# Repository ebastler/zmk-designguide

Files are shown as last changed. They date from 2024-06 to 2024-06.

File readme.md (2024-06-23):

## Please note: This guide in its latest revision has just been published and may contain spelling mistakes as well as explanations referring to wrong components due to being written at an earlier stage, before re-annotation of the schematic. Please report any possible erorrs.

## Introduction

Since it's launch a few years ago, [ZMK](https://zmkfirmware.dev/), an open source firmware for (mainly wireless) custom keyboards, has grown in both features and userbase rapidly and I have recently designed multiple boards making use of it in the past. Questions about how to design ZMK compatible hardware have been getting more common, and the first edition of my guide was a crude attempt at answering those. The third revision - which is only the second revision of the guide, but based on the third generation of wireless designs I made - is a more advanced and refined approach. It still contains all Rev 1 circuitry, but with small improvements, and multiple more "advanced" alternative schematic snippets, as well as better explanations and descriptions.

Most keyboard design guides focus heavily on QMK (and QMK compatible MCUs). While ZMK works flawlessly on STM32 (e.G STM32F303) and PCBs for those can be designed the same way as QMK compatible PCBs would be, the main appeal of ZMK is wireless operation, and I will focus on a nRF52840 based design in this guide. Keep in mind, this is no official ZMK team related guide - just a reference implementation from a user, for users. If you notice any errors, please report them either through github, or by contacting me some other way in order for me to fix them.

This is a rather advanced guide that expects some basic electronics knowledge, as well as design and routing experience. If you do not have those, i would recommend going over the [ai03 PCB design guide](https://wiki.ai03.com/books/pcb-design/page/pcb-guide-part-1---preparations) first. It's a great explanation of most basics needed to design your first keyboard.

Many symbols (and/or their matching footprints) in this guide are taken from [marbastlib](https://github.com/ebastler/marbastlib), a keyboard-focused open source library of kicad footprints and symbols maintained by me and [MarvFPV](https://github.com/marvfpv). While it is possible to use different libraries, I recommend sticking to it, since it's footprints/symbols are tested and confirmed working. While it used to be installed as a submodule to the project folder, we have now moved it to the KiCad pakcage manager system with KiCad 7. An installation guide can be found in the repo linked above.

## Table of contents
* [Introduction](#Introduction)
* [What do I need for a Bluetooth keyboard?](#What-do-I-need-for-a-Bluetooth-keyboard)
* [This is too complicated for me!](#This-is-too-complicated-for-me)
* [Schematics and design considerations](#Schematics-and-design-considerations)
    * [USB connector and protections](#USB-connector-and-protections)
    * [Battery management](#Battery-management)
    * [MCU](#MCU)
    * [Switch matrix](#Switch-matrix)
    * [Optional - Vsense](#Vsense)
    * [Optional - Underglow](#Underglow)

## What do I need for a Bluetooth keyboard?
This section lists the important parts, as well as some basic considerations. Detailed explanations follow below. There is plenty of compatible parts that work well, some may even work better than the ones I chose. This is, however, focused around parts I am familiar with and have already prototyped to ensure proper operation. I will list multiple options, ranging from simpler to more complicated and advanced, usually also more expensive choices. Which is right for you depends on your budget, capabilities and requirements, so I opted for leaving you with multiple choices.

* **USB Port and protections**: For flashing, possible wired operation and, most importantly, charging, you still need a USB port. I went with a USB-C port. The HRO M12 and M14 type connectors are cheap and easy to source, easily hand-solderable and routable and provide great mechanical stability. The protections I chose on this PCB are a good compromise between cost, PCB estate and protections - offering enough protection for a keyboard, while being easy to route. I added a JST 4-pin SH connector as an alternative, which can be used to connect an ai03 unified compatible USB daughterboard.

* **Battery management**: There's lots of different controllers for this application. I will show you two possible choices, a cheaper and a more expensive (but also more feature-rich one). They both are available at jlcpcb for prototyping, easy to route, and offer programmable charge current - allowing to set it to the maximum USB 2.0 allows (500 mA). Power switches are optional, due to ZMKs astonishingly low idle power draw, but examples were included anyway. 

* **Battery**: Not much to say here. Pick any decent LiIon/LiPo single cell battery that fits your keyboard. More capacity = longer battery life. You can consult the [ZMK Power Profiler](https://zmk.dev/power-profiler) to get a rough estimate of your expected battery life. Try not to poke it with sharp objects (switch pins on high-flex plate designs! Ideally add a protective FR4 or Alu plate between battery and switch pins) or reverse the polarity while connecting it to the PCB if you don't want to burn your house down. Batteries are awful.

* **MCU**: All is based around a Bluetooth enabled, ZephyrOS capable MCU. In my case, I went with an nRF52840 due to good software support and hardware availability, as well as Bluetooth 5 Low Energy capability. I recommend using a dedicated module instead of the bare chip, due to those offering a wide range of certificates (proving your board won't alert the white vans with the big antennas on the roof), because nRF52840 are rather annoying to route, and it's impossible to reach all pins without 4 layers and microvias, which are serious price-driving options. In this tutorial I will go over two different modules, which each have their pros and cons. There is countless other choices, so I recommend you look for yourself which of the [extensive list of certified modules](https://www.nordicsemi.com/Nordic-Partners/3rd-party-modules) best fits your needs.

* **Optional: Voltage sensing**: ZMK supports battery charge reporting over Bluetooth - handy to know how much runtime you have left. Depending on the module you use, and the accuracy you want to achieve, multiple options will be discussed.

* **Optional: Underglow**: ZMK supports WS2812/SK6812 adressable LEDs for underglow. An additional power cutting circuit that completely cuts the LEDs from the supply voltage while turned off is recommended, because those have rather high idle draw at ~1 mA per LED even when off and will chew through your battery in no time. Unless your design uses beefy batteries, I would recommend omitting LEDs in general - blinking lights are pretty, but months of battery life are even nicer in my opinion. With a power cutting circuit you give the user the option to choose.

## This is too complicated for me!
[Back to top](#Table-of-contents)

Well, don't despair. There are easier ways of making wireless PCBs - there is multiple Arduino Pro Micro compatible devboards sporting an nRF52840 chip, for example the [nice!nano](https://nicekeyboards.com/nice-nano/), designed by a ZMK team member, nicell. These boards take care of (almost) everything mentioned in this guide for you, enabling you to make a wireless keyboard without bothering with all the crazy tech-talk.

If you are like me, however, and enjoy a challenge, and are up to learning something new - let me be your guide, and show you around the crazy world of wireless keyboards!

## Schematics and design considerations

In the following chapters I will show (tested!) sample schematics for all relevant parts mentioned above, explaining the most important components, as well as my design considerations behind various components.

### USB connector and protections
[Back to top](#Table-of-contents)

J1 is a basic USB Type C 2.0 connector, as used in most modern custom keyboards. I recommend using either HRO Type-C-31-M-12 (regular top-mount) or HRO Type-C-31-M-14 (mid-mount) as they are proven, reliable and easy to source. 

R1 and R2 identify the board as a client for Type C hosts (like smartphones or notebooks connected with a C to C cable). The ferrite beads L1 and L2, together with the input caps of the board, form a low-pass filter to eliminate incoming HF noise, induced over badly shielded cables or by GPU/CPU voltage regulators in the PC. 

An electrostatic discharge applied to keyboard ground, however, must be able to pass to host GND (and therefore, Earth), but would be blocked by the low-pass as well. For this a suppressor diode is placed in parallel, which allows for high voltage discharges to flow freely. 

Since the [USB-C specifications](https://www.usb.org/document-library/usb-type-cr-cable-and-connector-specification-release-23) (Table 3-10) state that all cables must internally short shield to connector ground, I have shorted them on the PCB as well, and only used a single ferrite bead with a parallel capacitor as a filter between connector and circuit grounds. Please ground the case to shield/connector ground only, and avoid having the keyboard case connect to circuit ground. 

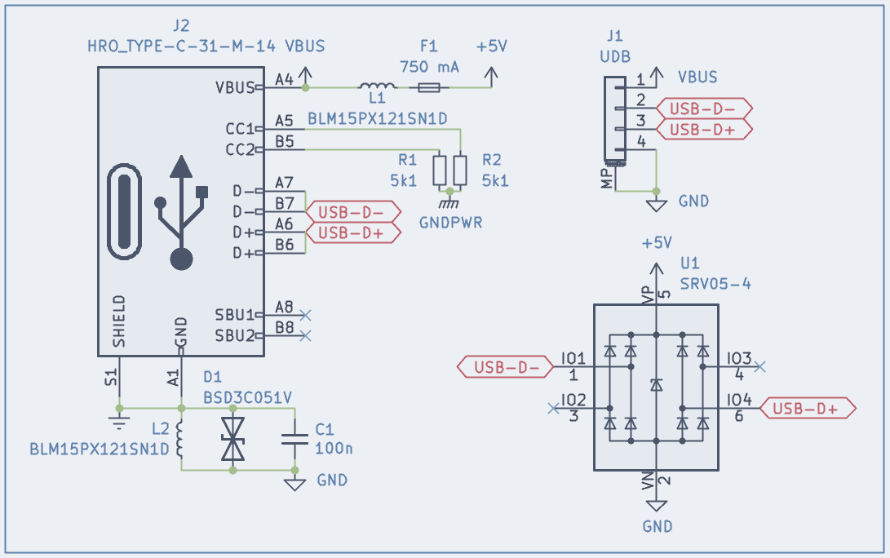
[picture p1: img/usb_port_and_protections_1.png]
Schematic of USB Port and protections


J2 is a 4pin JST SH connector with the correct pinout to be used with the ai03 unified daughterboard standard. It would for example be compatible with [the various ai03 unified revisions](https://github.com/ai03-2725/Unified-Daughterboard). No ground filtering is present on this connector, since it is expected to be done on the daughterboard. If you plan on using an early/cheaper version without filtering, connect it before the input filters instead.

U1 is a cheap and widely used dataline-protector diode + TVS array. It can protect up to 4 data pins (only 2 are used in this case, you could use the remaining two for CC1/CC2 datalines) against voltages higher than VBUS or lower than GND, and the integrated TVS will dissipate any voltage higher than 5 V (or lower than GND) on VBUS. Together with the fuse (F1) this forms an effective crowbar-like protection circuit against over-voltage or reverse-voltage on the supply lines.

### Battery management
#### Simple implementation
[Back to top](#Table-of-contents)

The TP4056 is a very wide-spread chip, available from a variety of brands and easy to implement. It is, however, not suited for powering a circuit while also charging a battery. It measures battery current to determine a fully charged battery, which will lead it to stop charging to avoid damaging the cell. For more information, check out [this blog post](https://www.best-microcontroller-projects.com/tp4056-page2.html). If the keyboard draws additional current, this threshold will be reached later (or not at all), leading to increased battery wear. That's what Q1 is used for - the Shottky diode `D2` will power the MCU directly off 5V USB instead of the battery while plugged in, while during battery powered operation `Q1` serves as an ideal diode (diode without significant forward voltage loss), supplying the MCU off the battery. 

Disclaimer: I have NOT prototyped the parts around Q1 yet, and most likely never will. I included it referencing the post linked above. Please consider the information given there, and proceed with caution. For a board without LEDs you may as well omit them - the current draw of an nRF52840 alone will not suffice to keep the TP4056 in charging mode.

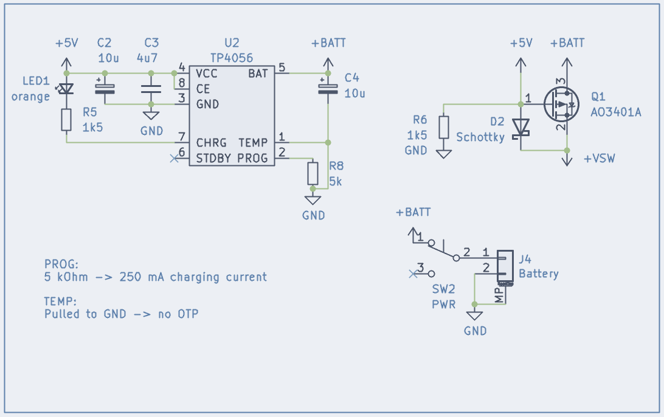
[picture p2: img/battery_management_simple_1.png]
Simple battery management schematic


The temperature sensor input is disabled in this implementation, since most cells used in keyboards bring their own, built-in temperature protections with them. The value for `R9` (`PROG` input) can be seen in the datasheet for the chip - 5 kOhm results in a charging current of 250 mA. Usually it should be between 0.5C and 1C (for a 500 mAh battery: 250 mA to 500 mA) - refer to your battery datasheet for actual recommended charging currents.

`LED1` serves as an indicator for the current charging state, and will be lit as long as the board is actively charging. The `STDBY` does the opposite, an LED connected to it would be off while charging, and turns on when the charge is complete. Both of these pins, paired with a dual-color-LED could be an interesting choice as well - red while charging, green once full.

`SW2` is a simple power switch to cut the battery from the system - watch out that the board will also be unable to charge as long as it is flicked off. In addition, the switch has to withstand the entire battery current - finding a sufficiently small footprint switch that can take up to 500 mA (or, in the case of our example, 250 mA) can prove difficult. If you want to omit the power switch, simply connect `+BATT` directly to `J3`.

#### Advanced implementation
[Back to top](#Table-of-contents)

The BQ24075 is an advanced "PowerPath" chip from Texas instruments. While the TP4056 is a pure battery charging chip, this one includes a whole lot of features. It will dynamically change the battery charging speed to stay within USB limits, depending on how much the board is drawing, and if a board with many LEDs should end up drawing more than 500 mA, it will even use the battery to temporarily supplement the excess current, in order not to overload the USB port. It also has a very useful "sysoff" feature, that can be used to switch the battery off without the whole battery current passing through the microswitch.

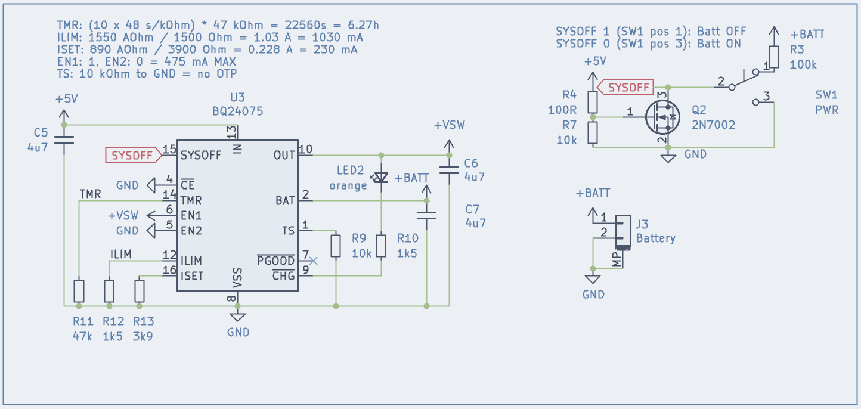
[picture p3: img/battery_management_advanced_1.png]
Advanced battery management schematic


The `EN1` and `EN2` pins decide the maximum allowed input current - depending on the configuration it can be 100 mA, 500 mA or "unlimited", where it can be controlled with an external resistor on the `ILIM` pin. Since keyboards are almost always powered by USB 2.0, I opted for the 500 mA limit. Meanwhile, `ISET` is used to choose the charging current. The formula is `R = 890 AΩ / U`, where `R` is the necessary resistor value, and `U` the charge current in Ampere. In our example we used `U = 250 mA`, hence `R = 890 AΩ / 0.25 A = 3400 Ω`. Since 3400 Ohm is not part of the widely available E12 resistor scale, we opted for `R = 3.9 kΩ`, which would result in a charging current of roughly 230 mA.

The `PGOOD` pin is the "power good" indicator, and shows that the chip is being supplied with stable 5 Volt over USB - this can usually be omitted. `LED2` however indicates that the battery is currently being charged - a very useful information as a user. If you want the power good status indication, add an LED the same way as LED2.

This slightly more complicated schematic makes use of the optional SYSOFF feature. If `SYSOFF` is connected to VBAT, the chip completely cuts the battery from the rest of the schematic. While this can sometimes be desired, it comes with a problem - it would not charge even when plugged in in this mode, which can be very frustrating if you forget about it. That's what Q2 is for. Q2 will pull `SYSOFF` to GND as soon as the board is plugged in for charging, re-enabling the battery as long as it remains connected to a stable USB power supply. Unlike the simple implementation, this switch does not have any significant current flowing through it, and can be chosen a lot smaller.

#### Additional battery management considerations
[Back to top](#Table-of-contents)

When using cylindrical batteries like 18650 cells or unprotected pouches, you should add additional protection circuits, since those do not offer any built-in battery protections like most pouch cells do. If you use regular, protected pouch cells as most boards do, you can skip this section.

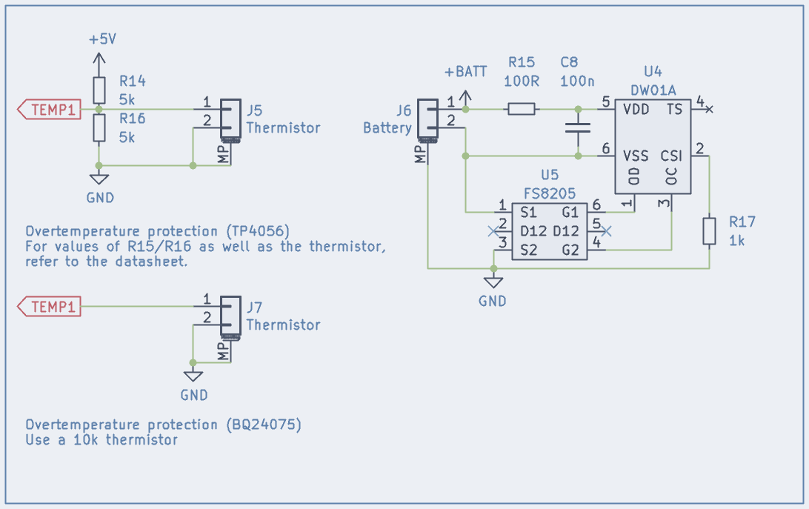
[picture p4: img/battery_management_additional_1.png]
Additional battery protections


In this case, adding a temperature sensor would be recommended - with USB 2.0 charging speeds it is basically impossible to overheat a cylindrical cell in common sizes, but additional precautions are always recommended (and, if you want to achieve FCC/CE certification, needed). On the TP4056 2 resistors and a connector for an external thermistor must be connected to the `TEMP` pin, instead of shorting it to GND directly. - for exact values, please consider the datasheet. The BQ24075 only expects a single `R = 10 kΩ` thermistor, connected between its `TS` pin and ground (it replaces `R9`).

An additional important protection is an undervoltage/overvoltage cutoff. For this application, the DW01A is a widespread chip, often used together with the TP4056, but it could be added to a BQ24075 schematic as well. The right schematic in the advanced section shows a possible implementation, which replaces the battery connectors present in the simple or advanced implementation. As you can see, the FS8205 double-MOSFET is connected between the negative battery terminal and circuit ground, allowing the DW01A to cut the battery from the board in any possible failsafe-case. 

If this event is triggered through undervoltage or a short circuit, disconnecting and reconnecting the charger should reset the chip. In the case of overvoltage, you should dispose of the battery, and connect another. 

### MCU
#### Holyiot 18010
[Back to top](#Table-of-contents)

As mentioned earlier, this guide will walk you through the use of two modules, the Holyiot 18010 and the Moko mk08a. The main differences between them lie in power supply and solderability. The holyiot has the big advantage that it can entirely be used with castellated side-facing pads, and hence easily be soldered with a soldering iron. As a disadvantage it has incomplete documentation and no exposed `VDDH` pin that would allow for a high voltage supply, so it needs an additional voltage regulator - `U6`.

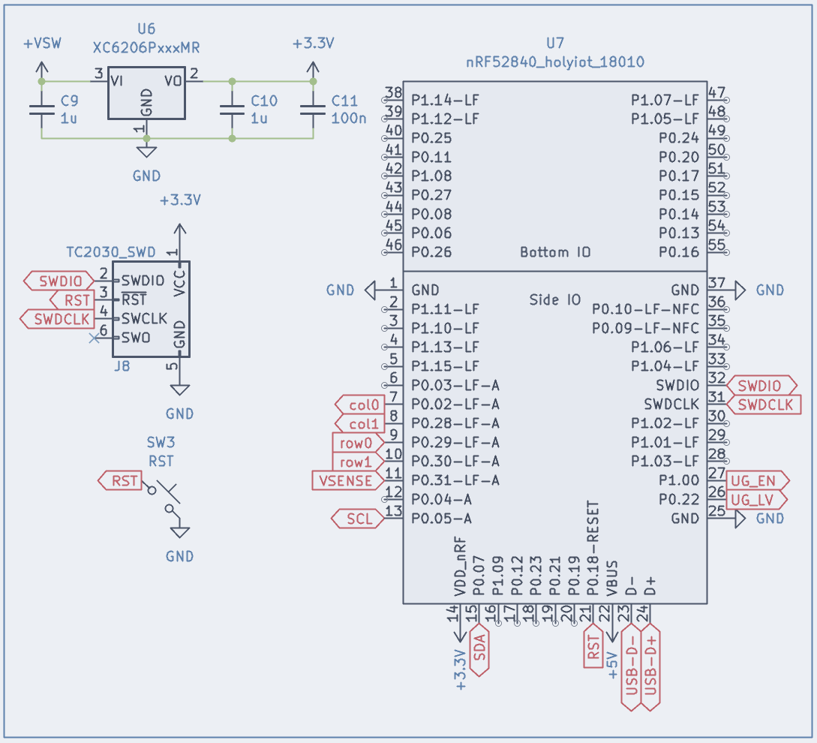
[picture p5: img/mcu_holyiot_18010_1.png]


The holyiot 18010 module uses the nRFs `VDD` pin for supply, which can be used up to 3.9 V. We supply it with an external 3.3V LDO. The `XC6206P330` has exceptionally low quiescent current (power dissipated in the device even without load), is easy to source and has a low dropout voltage (the minimum difference between input and output voltage), making it an ideal choice for this application. 

The `VBUS` pin of the module is used for USB plug detection and should be wired to the fused USB supply voltage (labeled `+5V` in this guide). Both battery schematics will work with this. `P0.18` is defined as a reset button in the adafruit bootloader I used and should be connected to ground via a small switch or tweezer-bridgeable pads. You will need this to enter the bootloader. `SWDIO`/`SWDCLK` must be wired to contact pads, because this is where the STlink/Jlink/BMP goes for flashing. I usually use a TC2030 connector for this, but unless you want to buy an expensive cable (up to 50 USD), it may be better to use a regular pin header or similar for it.

`VSENSE` must be connected to a pin which offers an analog input.

`UG_LV` (the WS2812 data pin) needs a pin that is not marked as "low frequency I/O". A full list of IOs and their capabilities can be found [in the nordic docs](https://infocenter.nordicsemi.com/index.jsp?topic=%2Fps_nrf52840%2Fpin.html&cp=4_0_0_6_0). Cols and rows can be set freely. If you want to minimize power draw at the cost of slightly more complicated routing, it is recommended to only use either P0.x or P1.x for matrix input pins (with a col2row diode setup, the rows). In our example we only have 4 switches, so routing them all to Port 0 is easy. If you plan on hand soldering, try to avoid the "Bottom IO" labeled IO section. You would need to reflow-solder the module for those to work.

`SCL/SDA` are only needed for a more advanced battery charge sensing, and need pins that are not marked as "low frequency I/O" as well.

#### Moko MK08a
[Back to top](#Table-of-contents)

The Moko is a slightly more advanced module, allowing for full HV mode. Quick detour into nRF52840 power management: The Chip operates at two voltage levels - "VDD" is the voltage level of all peripherals - your IO pins will use this voltage, usually 3.3 V. The core operates at an even lower voltage of usually 1.8 V. Additionally it offers a "VDDH" voltage level, which must be higher than VDD, and up to 5.5 V. Now, the nice part - the chip can generate all voltages directly off VDDH itself - either through internal linear voltage regulators, or even using internal DC-DC regulators for even higher efficiency. These need external capacitors and inductors to work though, and not all modules have those components onboard. The Moko does. Therefore you can directly supply it from battery voltage, and you even get higher efficiency (and battery life) than a Holyiot 18010 module could. Big downside of this (and all other modules with this feature) - it has pads at the bottom that are necessary for operation, so it is impossible to hand solder. While this may not be an issue for a larger production run where everything gets reflowed anyway, it is an issue for a small production at jlcpcb, or a hand soldered design.

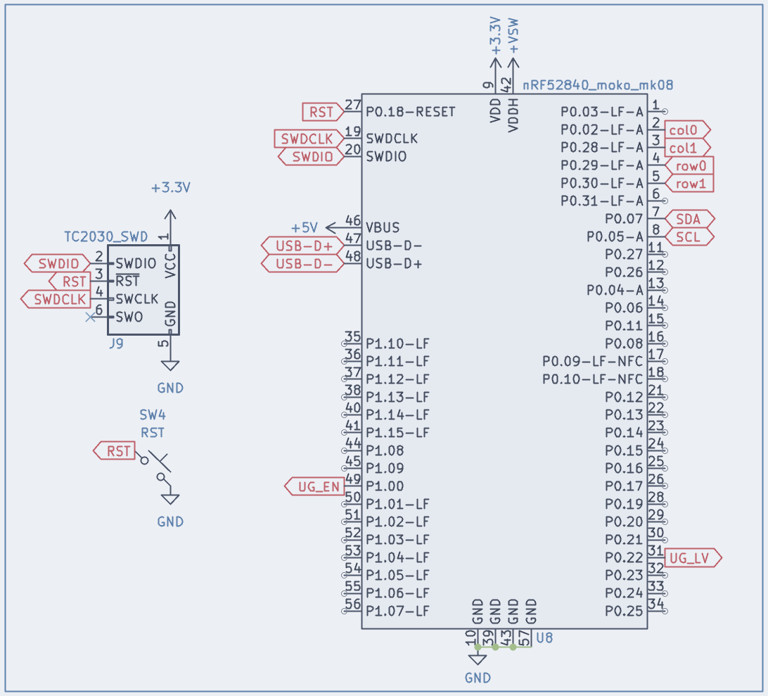
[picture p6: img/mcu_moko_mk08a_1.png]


`VDDH` needs to be connected directly to the output of the battery management schematic, as it is used to power the board. `VDD` serves as an output in this configuration, supplying (very low power) 3.3 V. We will need this to supply the programming port, and if used the levelshifter for the WS2812 signal later on.

A dedicated voltage sensing pin is not needed for this schematic, since the nRF52840 can use `VDDH` for voltage sensing as well, all other pins are handled the same way as on the Holyiot.

#### Ebyte E732G4M08S1C
[Back to top](#Table-of-contents)

The ebyte is a similarly capable module as the Moko, but unlike the Moko does not contain all components needed for DC-DC HV mode. It does, however, have all necessary pins exposed so that we can add the missing components externally - the inductor `L3`, together with the powerstage integrated into the chip, and the etxernal filtering capacitor `C12` gives this module full DC-DC capability. Keep connections between module, `L3` and `C12` as short as possible, in order to keep the loop length of the DC-DC switching node short. An excessive loop length will lead to increased EMI. 

This module also lacks an integrated LF crystal, which needs to be added externally (`Y1`, `C15` and `C16`) in order to benefit from ZMKs deep sleep capabilities, which disable the more power intensive high frequency oscillator.

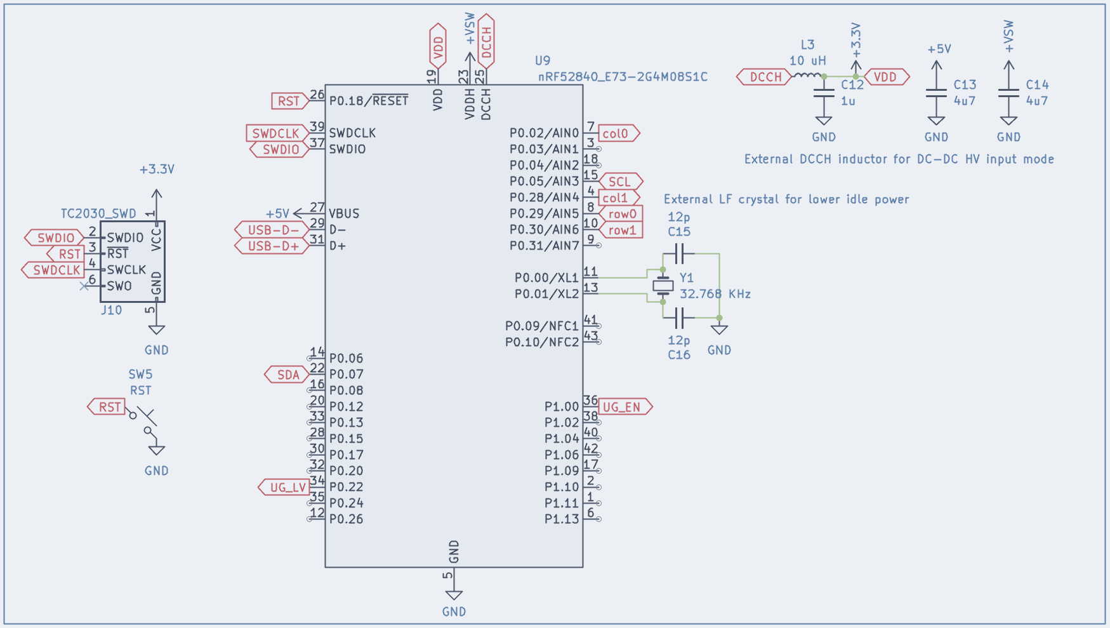
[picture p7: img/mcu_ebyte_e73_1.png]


### Switch matrix
[Back to top](#Table-of-contents)

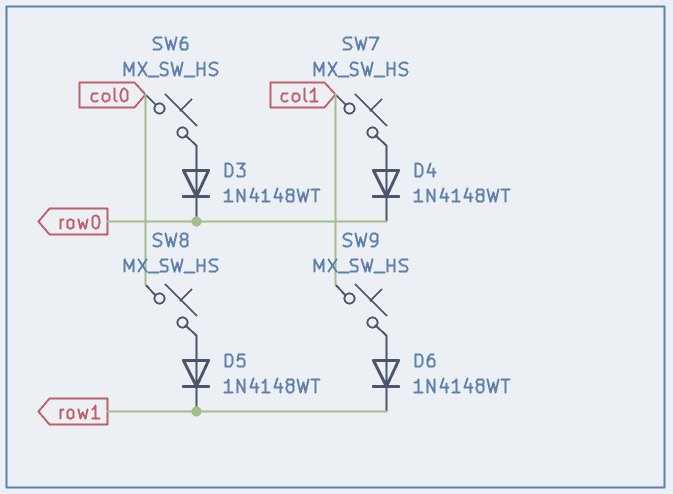
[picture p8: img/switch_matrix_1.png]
switch matrix


Not much to see here. Just a generic 2x2 switch matrix. I used 1N4148WS, but most signal diodes will work just as well. SOT-23-3 common cathode diodes like BAV70 can help reaching a clean PCB look on ortho/row stagger, but are annoying to use on col stagger boards.

### Vsense
The easiest approach for voltage sensing is measuring the battery voltage directly. On the Holyiot you'll need a voltage divider to get the battery voltage down to safe levels for the MCUs 3.3 V capable GPIOs. For this we use a voltage divider. The values have been used on the [nice!nano v1](https://nicekeyboards.com/nice-nano/) and have since become a de-facto ZMK standard, though changing them is no problem - the values are defined in firmware and can be set to any values. Make sure you stay within a similar range of total resistance and calculate the highest possible output voltage if you decide to change the values, though.

The Moko Mk08a and Ebyte E73 in HV mode can directly measure VDDH voltage, no divider or dedicated pin is needed for it.

The disadvantage of this approach is, that LiIon cells have non-linear discharge curves. They drop to about 4 V quickly, then remain between 3.6 and 4 V for a longer time, and in the end drop off quickly once more. Measuring voltage alone is not enough if you want to have precise battery percentages. ZMK does account for these nonlinearities, but dedicated fuel gauge chips which allow for higher accuracy exist as well. The [MAX17048](https://datasheets.maximintegrated.com/en/ds/MAX17048-MAX17049.pdf) we use here is a bit of an outlier, since it does not measure current through shunts (and therefore the mAh charged/consumed). Instead it relies on voltage measurements, but combined with advanced algorithms. This allows for an inexpensive, small and easy to integrate chip, that still reaches high accuracy.

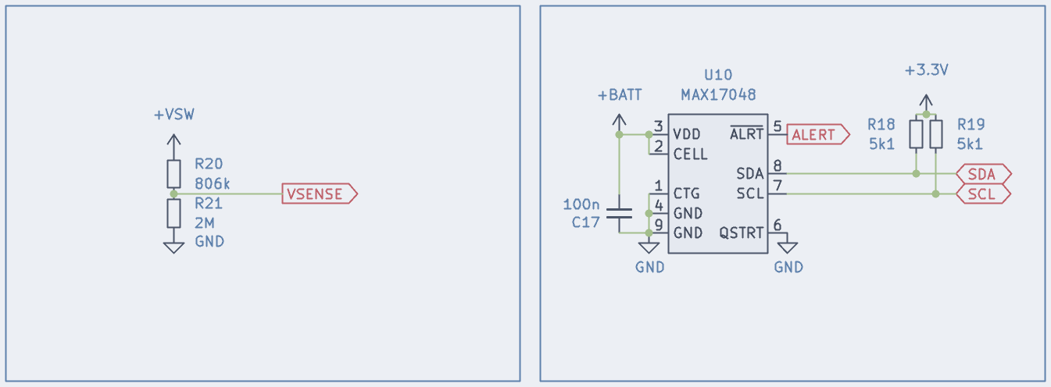
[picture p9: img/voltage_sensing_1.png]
vsense


### Underglow
[Back to top](#Table-of-contents)

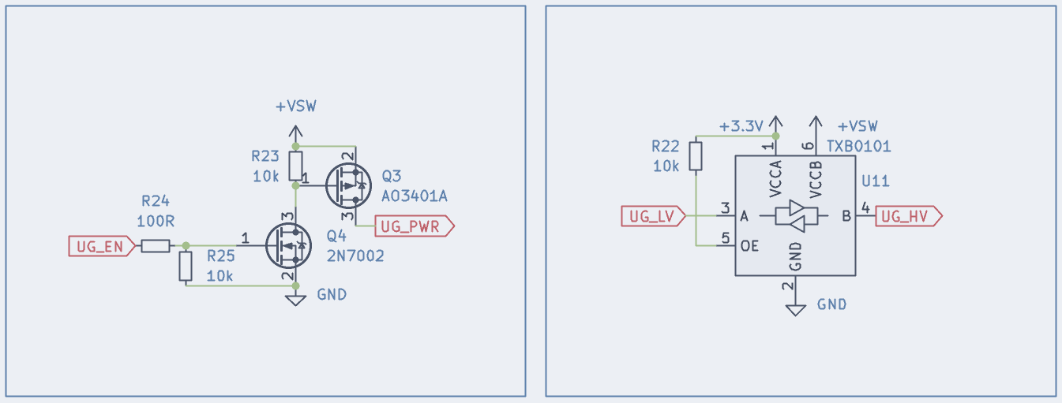
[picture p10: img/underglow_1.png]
underglow control


This schematic consists of 2 parts. The left allows us to completely cut supply voltage for the underglow when it is disabled (ZMK does this automatically), saving up to 1 mA per LED quiescent current - and therefore increasing battery life by multiple orders of magnitude. If the LEDs are turned off, `UG_EN` is low, therefore the gate of `Q4` is low, and the gate of `Q3` is high - this leads to no current flowing anywhere in the circuit. Once `UG_EN` is high, so is the gate of `Q4`, which in turn pulls the gate of `G3` low. In this state, both 10k resistors allow current flowing to GND, but compared to the LED current the current through both resistors is negligibly small.

The right schematic is a levelshifter, intended to translate the 3.3 V signal level from the MCU up to battery voltage level output. SK6812MINI need 3.4 V for a logical high, while WS2812 only need 0.7 times Vcc, which would be 2.95V on a full Li battery cell. The WS2812C_2020 used in this example [work with 2.7 V](https://cdn.sparkfun.com/assets/e/1/0/f/b/WS2812C-2020_V1.2_EN_19112716191654.pdf). The levelshifter can usually be omitted, since most types of adressable LEDs are proven to work with 3.3 V signal level - I included it as an example since you may need it to run some LEDs in spec. In case of doubt, check your desired LED's datasheet. Most need 0.7 times Vcc signal level, which can easily be reached without a levelshifter. The WS2812C_2020 used here would not need it either. All others (like SK6812MINI) should work without one too, though out-of-spec. Use at your own risk.

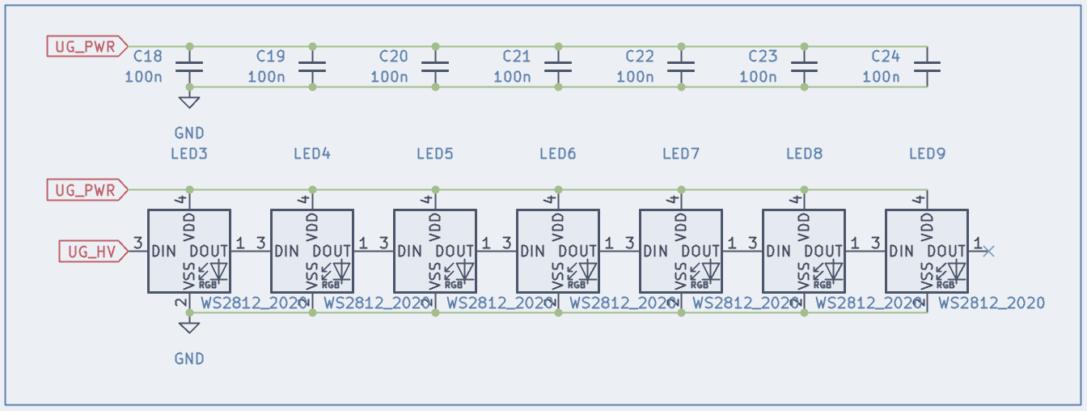
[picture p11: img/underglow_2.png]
underglow leds


The LEDs are straightforward - make a chain, connect Vdd to your power source (UG_PWR flag in this case) and the data pin to either UG_HV (if you want to use the levelshifter) or UG_LV (if you address them directly from the MCU). Don't forget to include the 100 nF cap which most addressable LEDs need and keep it close, but double-check with the datasheet. Newer revisions may not need those anymore.

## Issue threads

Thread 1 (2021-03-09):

suggestion: protection for battery reverse polarity

ergodone, 2021-03-09:
My understanding is there is no protection for a reverse polarity battery connection in the current design.  I think that would be a useful addition since there seems to be no standard for the orientation on the battery connectors (at least the batteries I ordered did not match my adafruit feather).

ebastler, 2021-03-17:
Thanks! That's a good point indeed. Most Schottky Diodes would cost ~.4 V though, which lowers the amount of energy that we can pull from a battery by quite a bit. I'll have to come up with a different idea.

The charging circuit already has a small flaw (If the board is left for multiple hours/days connected to a charger, with LEDs running, the charger will not correctly determine end of charging, and hold the battery at 4.2V which will damage it over time). Workaround will be implemented.

Percentnineteen, 2022-01-26:
Could use a  channel mosfet between By and GND with B+ as the gate. I think it's done that way in mitosis

Tsangan1, 2025-06-05:
> The charging circuit already has a small flaw (If the board is left for multiple hours/days connected to a charger, with LEDs running, the charger will not correctly determine end of charging, and hold the battery at 4.2V which will damage it over time). Workaround will be implemented.

Hey, I know this was already 4 years ago - but has it been fixed yet? Or would there be and "easy" way too implement it by myself?
 (in the end, any way would be fine, aslong as it fixes it, but of course an "easy" one would be nicer 😄)
I am a little scared about it if I am being honest, so I Just wanted to ask 😅 Thank you!

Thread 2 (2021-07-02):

Question about UG_EN

eigenbrain, 2021-07-02:
Hi Ebastler,
First of all, thanks for the wonderful material that you are sharing. I am very new to the integrated board design, and your material is of great help. On your schematic, there is UG_EN pin, which controls the underglow circuit. Can you let me know how I set this pin in ZMK firmware configuration?

ebastler, 2021-07-03:
Hi eigenbrain,

glad you like my guide - I'm super proud how many people are using it as a reference for their designs.
I got the UG power toggle working on my isometria 75, mostly by copying the nice!nano - check out the linked line in the *keyboard*.dts file: https://github.com/ebastler/zmk/blob/isometria75-rev2/app/boards/arm/isometria75_rev2/isometria75_rev2.dts#L68

It was on GPIO 1.15, you'd have to replace the <&gpio1 15 GPIO_ACTIVE_HIGH> with <&gpio0 4 GPIO_ACTIVE_HIGH> for the pin chosen in the design guide.

noclew, 2021-08-17:
what a nice guide this is. Thanks for putting this together!

eigenbrain, 2021-08-17:
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

Thanks for the detailed explanation, and sorry for the late check. Now I am making my first ZMK board following your guide and am so excited.

By the way, if I end up having the PCB ready, gan you let me know how I can flash the keyboard? I read that you used STLink, but I am too new to guess how it works. If there is any good resource to see how I can make it work like nice!nano, which gets into the bootloader mode when the reset button gets double clicked, can you please point me where to look?

ebastler, 2021-11-30:
Sorry for the late reply - I totally missed the issue you opened.

First of all - good luck with the PCB design! I guess you already finished by now, but I'll address your questions anyway. Better late than never.

1) I was asked about this in another issue today, will link the answer here: https://github.com/ebastler/zmk-designguide/issues/3

2) The behavior you describe is the default Adafruit BL behavior - if you follow jorics guide in my linked explanation, it will work that way.

3) the holyiot docs suggest having the antenna protrude over the PCB edge. I did not have the space necessary to do that, but I guessed adding a hole below the antenna would be better than nothing. I can not tell whether or not it actually helps. Signal strength on the isometria is solid.

Kind regards and sorry once more for the late reply!

Closed 2022-10-11.

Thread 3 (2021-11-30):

Question about SWDIO/SWDCLK

Forge-Media, 2021-11-30:
I'm looking to build a custom Bluetooth 60% PCB, I've stumbled on your guidelines which are amazing and proving really useful. I've previously designed a working 3x3 macropad following ai03's guide, so have some experience, but introducing Bluetooth, a battery and zmk is all new.

I was initially going to just use a Nice!nano v2. But since reading your guidelines I'm hoping to do it all myself, using a Holyiot 18010.

> Under the MCU section regarding SWDIO/SWDCLK these must be wired to contact pads, because this is where the STlink/Jlink goes for flashing.

This part has me a little confused. I've not used zmk before, but from reading the docs flashing sounded quite simple,  place board into bootloader mode (double press the reset switch) and drop the UF2 file onto it. However, from reading your guidelines it sounds that there may need to be more work involved to get the Holyiot 18010 flashed before flashing zmk?

- Does the Holyiot 18010 come without a pre-loaded boot loader/require first flashing the Adafruit nRF52 Bootloader?
- Is it possible to have the Holyiot 18010 supplied with the Adafruit nRF52 Bootloader pre flashed?
- Could you go into any detail about what is involved with STlink/Jlink for flashing or are there any other references you could link me to?

Thanks

ebastler, 2021-11-30:
Hi,
Sadly all nRF52 modules I know of (apart from maybe adafruit ones?) come without any bootloader, and unlike some stm32 chips the nRF52 series does not have a in-built bootloader in ROM.

Once the bootloader is on, flashing is - as you pointed out - super simple and can be done via USB UF2 drag and drop. In order to get the bootloader on the module, you need either a STLink (works only for unlocked modules, holyiots appear to always be unlocked) or a Jlink (works for locked or unlocked modules).

For flashing you need a computer running the openOCD tool (i have only used it on Linux so far, not sure if there is a windows/mac version of it), and the flashing itself boils down to 1-2 commands, depending on whether the module has a locked or unlocked BL (only 1 for holyiot).

Joric wrote a good wiki article regarding flashing, i linked you the stlink section. Jlink is right below. You only need the "flashing" command on a 18010, not the "unlocking" command.
https://github.com/joric/nrfmicro/wiki/Bootloader#st-linkv2

Hope I could help!
Moritz

Forge-Media, 2021-11-30:
Thanks, will take a look at the link.

Flashing the bootloader still seems to be the one thing I'm most nervous to tackle. I'm hoping any equipment I need won't be too costly.

 do you think it's possible to have the Holyiot 18010 supplied with the Adafruit nRF52 Bootloader pre flashed or have someone like PCBway flash it for you if I'm paying for assembly?

ebastler, 2021-11-30:
Hi! A Jlink will cost you ~20$, a STlink v2 Clone used to be 1-2$ on Aliexpress, nowadays they are around 3-4$ as far as i know (chip shortage...). Still very affordable and all you need. The most difficult part is to install openOCD (you have to compile it from source on Linux), but that boils down to ~5 commands I can dig up from my chat history from the last time I explained it to someone if you should need it - no clue how much experience with Linux you have.

Usually PCB fabs offer flashing for assembled boards, but I have yet to try if that works for nRF chips too. I guess it should.

Forge-Media, 2021-11-30:
Thanks, that would be highly appreciated. I've a fair amount of Linux experience with servers, though all cloud and virtual. Don't have a dedicated Linux machine at home apart from a Raspberry pi 4, which seem could be an option with OpenOCD according to the link you provided and I won't need to purchase anything else.

I'm not really sure I trust the assemblers to flash it more than myself. 😅 But the cost for the equipment is not really an issue, was more worried it would be much higher and more difficult to find in stock.

ebastler, 2021-11-30:
I tried getting openOCD to run directly on a Pi3b, but failed. Not sure if I missed something. Sadly docs for how to configure openOCD directly on a Pi are sparse. I ended up using the STlink v2 connected to the Pi via USB - that worked fine.

Forge-Media, 2021-11-30:
Ok that's good to know, I may order an STlink v2 in that case.

Forge-Media, 2021-11-30:
One last question, did you purchase the Holyiot 18010 directly from the manufacturer and did you you hand solder it to your PCBs or have them soldered as part of a PCB assembly service?

ebastler, 2021-11-30:
I ordered mine off Aliexpress, I think it was their official store. As long as you only use the outer pads, they are super easy to hand solder.

Forge-Media, 2021-12-01:
I contact Holyiot via email to ask about the bootloader and they told me the following:

> Yes, we can pre-program your hex file before shipping.
> We provide this service for free now and in future.
> Please place the order and leave the message on Aliexpress at the same time.

I'm thinking this may be a good idea. But thought I would ask which bootloader version you used. I'm assuming there should not be any issue sending them the latest; [pca10059_bootloader-0.6.2.zip](https://github.com/adafruit/Adafruit_nRF52_Bootloader/releases/tag/0.6.2)

I did read on the ZMK discord I could build my own version of the Adafruit bootloader, and flash that. This was suggested by a user called petejohanson and he linked to his custom bootloader: https://github.com/petejohanson/Adafruit_nRF52_Bootloader/tree/technikable/src/boards/technikable

Besides specifying the pin of the the user LED, and showing a custom mass storage device name to the OS. I'm not sure if there is an advantage to building my own bootloader versus using the pca10059_bootloader-0.6.2.

ebastler, 2021-12-01:
Okay, that is super cool. Didn't know they offered this service. I'd go for it.
I think I just used the default adafruit one for my isometria, can't really remember though to be honest. Pete is the project lead of ZMK, so he sure knows what he's doing, but without any deeper research I don't really see the advantage in doing so either.

Closed 2022-10-11.

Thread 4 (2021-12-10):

Question about battery connection.

BeefcakeTheMighty, 2021-12-10:
Thank you for all of the work you've put into this project and for sharing it; it's awesome!

I'm not understanding how the battery powers the MCU. I see VBAT out on the battery management and VBAT in on the voltage reg., VSENSE, and underglow. It appears that the only power the MCU receives is directly from USB-D+/-.

Also, I'm not seeing what VBUS on the USB-C connector supplies.

Maybe I'm just missing something super simple; any guidance you can provide is much appreciated!

ebastler, 2021-12-11:
You're welcome - glad you like it!
Regarding your first question - the MCU can't take the full VBAT, hence VBAT is passed through the voltage reglator (the section between battery management and the MCU in the guide), which outputs stable 3.3V for the MCU (module).
The 5V pin on the MCU is only used as a USB plug detection (and I think powers the USB peripheral), but not the MCU itself. That one is powered by the 3.3V on pin14.

VBUS on the USB-C connector is the 5V pin of the connector, called VBUS since it's the supply voltage delivered by the USB bus - I call it 5V after the fuse.

Hope that answers your questions - if I missed a point, feel free to ask :)

Cheers,
ebastler

BeefcakeTheMighty, 2021-12-11:
Oooohh...yup...I see it now. I was focusing too much on the "direction" of the wires and should have paid more attention to the nrf documentation.

I think you covered all my questions! Thank you!

The only one I have remaining is:

Are all the 5V+ tied to the same "rail"? I.E. the 5v/VBUS supply on the usb-c (through U2), the two on the battery mgmt. (assuming I calculate my own R14 & R16 and use a stand-alone thermistor), and the 5v pin/VBUS on the MCU (module)?

Thanks in advance!

ebastler, 2022-10-11:
Hi! I am terribly sorry, I must have missed this comment - only saw it now, almost a year later. Guess you don't need it anymore, but yes, all +5V labeled nets are supposed to be a single net!

Closed 2022-10-11.

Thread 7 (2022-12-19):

Ask: Please provide the ZMK config

LamDVT, 2022-12-19:
Thank you for your project. It's awesome!
I used your guide and it worked correctly.
Can you provide your ZMK config (used to run the hardware in the tutorial) for us to refer to and follow?
Thank you very much!

ebastler, 2022-12-19:
For the firmware:
https://github.com/ebastler/zmk-config/tree/main/config/boards/arm

Bootloader:
https://github.com/ebastler/Adafruit_nRF52_Bootloader/tree/ebastler/src/boards

altar is a holyiot + voltage divider based board

wlpad is a Moko + Fuel gauge based board

Both use bq24075, but that doesn't really affect the code.

doantruonglam, 2022-12-20:
Thanks forThanks for your quick answer.
I'm having problems with UG_EN can't activate UG_PWR for ws2812. I followed the instructions here: https://zmk.dev/docs/config/power but failed, I would like to refer to your source code to configure this section.
Thank you.

ebastler, 2022-12-20:
Oh, that's the issue - check my Isometria 75 code. That one is using a Holyiot with UG_PWR toggle!

doantruonglam, 2022-12-20:
Your answer is very helpful with me!
Last question: I do not need care about the line `ALERT ` in "Voltage sensing (advanced)", right? Can I use both `MAX17048` and an OLED I2C by connect to the same `SCL, SDA` lines?

ebastler, 2022-12-20:
I didn't use the Alert yet, the driver doesn't make use of it either I think. I have not tried OLED + Chip, but shouldn't be an issue - i2c is made for multiple devices on the same bus.

Just one thing: the driver for the fuel gauge is not officially merged into ZMK yet.

I have merged the driver and patched an issue with it on this branch of my fork: https://github.com/ebastler/zmk/tree/testbranch

You can use that, I will try to set the PR in motion these days, so hopefully it will sonish be working with the main ZMK.

doantruonglam, 2022-12-21:
I'll give it a try. I think it should work properly.
Thank you for your support.

ebastler, 2022-12-29:
No problem, hope you get your design working!

Closed 2022-12-29.

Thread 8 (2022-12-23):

P channel mosfet in underglow example seems to be flipped

sadekbaroudi, 2022-12-23:
https://github.com/ebastler/zmk-designguide#Underglow

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

I sent this as a reference on how to to LED firmware enable / disable in ZMK, and someone (Dasky) noticed that it's flipped. Can you confirm?

ebastler, 2022-12-29:
Damn, you are absolutely right about that - thank you very much for pointing it out, will fix. This is a serious flaw.

ebastler, 2022-12-29:
Fixed in 1b4583ed1fe225307f807862ee2afc1a4a0c8ec5 - thanks for reporting!

sadekbaroudi, 2022-12-29:
No problem! Thanks for the quick fix @ebastler

Closed 2022-12-29.

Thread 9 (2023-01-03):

USB ESD Protection Labels wrong?

OAreiqat, 2023-01-03:
The labels on the ESD Protection module seem to be inconsistent with the rest of the schematic. Am I not sure if that's normal or not so I am bringing this up just in case

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

ebastler, 2023-01-17:
Did not notice, thanks for pointing it out! I will fix it as soon as I find the time. Copied parts of the designguide from projects of mine, and that used a different ESD chip which needs other labels.

ebastler, 2023-04-04:
I just noticed I only fixed it in the schematic, not yet in the screenshots... Will have to re-take those.

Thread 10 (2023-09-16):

Leds data pin connected to low frequency output

tomy983, 2023-09-16:
https://github.com/ebastler/zmk-designguide/blob/feaae1f7793e591d2afa24e0e63899b38bbce676/readme.md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

In the readme you state that a low frequency pin should not be used for the leds data, but in the pictures and schematic you show the leds data output attached to `P0.09` of the MCU wich is a low frequency pin.

ebastler, 2023-12-30:
Mh... This must be something I missed when I drew the guide schematic, the labels on the symbol were only added later on.

Thanks for pointing it out, will fix when I have the time.

ebastler, 2024-06-23:
Sorry it took me so long to address! Moved the pins now.

Closed 2024-06-29.

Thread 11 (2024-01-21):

holyiot 18010 uf2 bootloader

michaelrommel, 2024-01-21:
Hallo Moritz,

entschuldige diese Art der Kontaktaufnahme, leider schlugen alle Varianten, Dich auf Discord oder twitter zu kontaktieren fehl.

Ich habe im Mosfetkiller Forum gelesen, dass Du mal eine Tastatur mit dem Holyiot 18010 Modul gebaut hast. Ich hab das auch gemacht, aber ich bekomme den Adafruit UF2 Bootloader einfach nicht zum connecten, wenn ich den Reset Taster doppelklicke, passiert ausser dem Reset (sehe ich auch nur an der Stromaufnahme) gar nix.

Ich bin jetzt etwas ratlos und suche nach jemandem, der den Bootloader zum Laufen mit dem Modul gebracht hat un dmir evtl. sagen kann, ob man ihn neu kompilieren muss und welche settings entscheidend sind, z.B. hat ja das holyiot Modul die DCDC Wandler aktiviert etc.

Hast Du hier vielleicht einen Tipp fuer mich oder ein repo, in dem ich mir Deine Loesung ansehen koennte?

Vielen Dank im Voraus!

  Michael.

ebastler, 2024-01-21:
Hi!

Kein Problem, passt hier ja auch ganz gut :)

Allem voran - hast du den Bootloader korrekt geflasht gekriegt? Also mit post-flash-check ohne Fehler? Klingt für mich in erster Linie als wäre der Bootloader gar nie drauf.

Die nRF kommen ab Werk mit Write Protection, vergessen viele die erstmal aufzumachen, dann schreibt der Flash nichts. Welchen Programmieradapter nutzt du?

An sich braucht das Modul nichts besonderes - ob man DC-DC beim Adafruit Zeug in der FW oder im Bootloader aktivieren muss erinnere ich mich nicht mehr, standardmäßig sollte es aber auf aus stehen. Welchen Bootloader hast du genau genommen? Selber einen zusammengestellt, oder einen der Sample BL verwendet?

Ich könnte Mal einen neuen Workflow in meinem Repo anstoßen, der Bootlader der Isometria war für ein Holyiot ohne irgendwas Besonderes ausgelegt. Dann hättest du wenigstens Mal eine BL Config die garantiert auf einem Holy lief zum Testen um eine Fehlerquelle auszuschließen.

michaelrommel, 2024-01-22:
Hi Moritz,

erstmal vielen Dank für die prompte Reaktion!

Zum Testen habe ich verschiedene Bootlader aus dem Adafruit Repo unter Releses probiert, habe keinen selbst kompiliert (aus macos selbst mit brew installerter Toolchain gab es Fehler, ich wollte als Nächstes mal einen BL auf Linux probieren zu kompilieren). Ich hatte recherchiert, dass der 10056 eigentlich haette funktionieren sollen.

Als Programmieradapter habe ich die Gpio Pins eines Raspberry Pis mit openocd genommen, damit hatte ich schonmal ein XIAO BLE Modul neu geflashed, wusste also, dass das prinzipiell funktionieren sollte. Das 'verify" kam auch mit "ok" zurueck.

sudo openocd -f interface/raspberrypi-native.cfg -c “transport select swd” -f target/nrf52.cfg -c init -c “reset init” -c halt -c “nrf5 mass_erase” -c “program Seeed_XIAO_nRF52840_Sense_bootloader-0.6.1_s140_7.3.0.hex verify” -c reset -c exit

Die Tastatur ist hier, (https://github.com/michaelrommel/nightliner), habe die linke Haelfte mal teilw. reflowed, alle SMD Komponenten auf der Vorderseite sind drauf. (OK, zwei habe ich wieder entfernt: hatte die Pinbelegung des USBLC6 falsch und habe den abgeloetet und ueberbrueckt, ebenso wie die Schottky Diode, weil ich ausschliessen wollte, dass der Voltage Drop auf ca. 4.8-4.9V nicht die Ursache des USB Problems ist.)

Von der von DIr genannten Write Protection hatte ich auch gelesen, weiss aber nicht, ob ich da die richtigen Kommandos via openocd gesendet habe.

dap apreg 1 0x04 0x01

Da der openocd connected und auch die Status Zeile "Info : nrf52.cpu: hardware has 6 breakpoints, 4 watchpoints" bringt, hoffte ich, dass dies erfolgreich war.

Wenn Du bestaetigst, dass eigentlich ein Standard BL mit dem Holy laufen sollte, bin ich geneigt, den Fehler auf meiner Platine zu sehen. Ich bin momentan unterwegs und habe keinenZugang zur Reflow Station und den weiteren Platinen, das Experiment "teilbestuecke eine Platine nur mit USB Socket, Voltage Regulator und Holyiot (+2x 5.1k und ein paar Caps)" muss also bis Freitag warten... Ich hoffte es sei ein SW Config Problem, die Tastatur und den Pi plus Macbook habe ich dabei...

Wenn Du wirklich ein Minimalworkflow fuer den Holy baust, waere das absolut super, dann kann ich mich daran lang hangeln...

Besten Dank und Grüße nach Berlin!

  Michael

michaelrommel, 2024-01-27:
Hi Moritz,

meine Tastatur laeuft nun grundlegend! Der Fehler lag daran, dass ich - nachdem ich den falsch verdrahteten USBLC6 ausgeloetet und ueberbrueckt hatte - das USB-C Receptacle nicht mehr sauber eingeloetet hatte. Die Stromversorgungs Pins hatten noch Kontakt aber die Datenpins nicht mehr. Mir ist das nicht aufgefallen, weil ich die Kontakte immer nur an den Pads gemessen hatte und nicht am anderen Ende des USB Kabels. Muss mir mal ein Breakout Board bauen, das die USB-C Leitungen testbar macht... Heute hatte ich mal versucht ein USB-C zu USB-C Kabel an einem Rechner zu nehmen und hatte keinen Strom (weil er die 5.1k Pulldowns nicht gesehen hat). Das kam mir dann spanisch vor und nun habe ich das komplette USB-C Receptacle getauscht und sehe nun die UF2 Partition. Puh! Ich hab mir die Haare ausgerauft, und dann nur eine kalte Loetstelle.

Aber ich kann nun bestaetigen, dass der Standard pca10056_bootloader-0.8.2_s140_6.1.1.hex Adafruit Bootloader ohne Modifikation mit dem Holy funktioniert! Vielen Dank fuer Deine Troubleshooting Tipps und fuer osprey, da habe ich heute nochmal Analogien zu meinem Board gezogen, da doch einige Bauteile gleich sind, war das eine super Referenz! Muss noch die Abweichungen versuchen zu verstehen: Du hast zwischen Shield/Earth und GND 100nF (ich nur 1nF) und dann hast Du noch sowohl zwischen GND und GND parallel zur TVS Diode BSD3C051V eine Spule BLM15PX121SN1D, und die ist auch noch inline im VBUS. Das muss ich mir mal in den Datenblaettern ansehen...

Jedenfalls kann mein Tastaturprojekt nun weitergehen... Lieben Dank nochmals,

  Michael.

Closed 2024-01-27.

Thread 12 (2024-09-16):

Where do GNDPWR and Earth connect to?

xpol, 2024-09-16:
Hi,

I'm a software engineer, Thank you for the guide!

I have a dumb question: In the "USB connectors and protections" section, there are GNDPWR and Earth besides GND.
So where do GNDPWR and Earth connect to?
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

ebastler, 2024-09-16:
Ugh that is a leftover from me overhauling the entire ground/shield handling. Sorry. GNDPWR should be regular GND. Earth is just a label and can stay there as-is. Earth should be what your enclosure is connected to, if the PCB gets put into a metal housing.

krikun98, 2024-09-16:
So is the old schematic with the 1M resistor from the Osprey no longer relevant?

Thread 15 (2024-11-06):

Exact value of resistor in SYSOFF section

billiororen, 2024-11-06:
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

Hi, first of all, thanks for your guidance. It was very helpful for me to design my own pcb for wireless keyboard.

In the SYSOFF section, you've specified R4's value as 100R.
I'm dumb for this circuit design knowledge, so I can't tell what this value is exactly.

Does the value means just 100Ohm? Or any other value?

ebastler, 2024-11-07:
Hi! I'm glad my guide helped you. The 100R is a simple gate resistor to limit gate current - not strictly needed and the value is totally not critical, as long as it does not approach the value of R7 (and forms a voltage divider that approaches 0.5 times input voltage on the output).

100R is one way of writing 100 Ohm, yes. The exact value is absolutely not critical.

Closed 2025-01-31.

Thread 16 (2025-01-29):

VSW?

vinniefranco, 2025-01-29:
First, thanks for this wonderful guide!

That said, I'm a bit thrown by the underglow portion of the guide. +VSW is labeled but not called out in the docs. What is this connection in the context of a WS2812C context where the level shifter is omitted? Thanks

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

ebastler, 2025-01-31:
Hi! +VSW is basically the switched battery voltage, as seen in section https://github.com/ebastler/zmk-designguide?tab=readme-ov-file#simple-implementation and https://github.com/ebastler/zmk-designguide?tab=readme-ov-file#advanced-implementation

In one case it is after the MOSFET ideal diode, in the other it is the system power output of the more advanced TI battery management chip

vinniefranco, 2025-02-04:
Thanks so much!

Closed 2025-04-01.

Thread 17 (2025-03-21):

Question about voltage of ws2812

Gasiro, 2025-03-21:
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

Hi ebastler,

Thank you for this guide! It has been incredibly helpful, especially since I had very little experience with schematic design before.

I have a question regarding the WS2812 LEDs. I’m not quite sure about the UG_PWR label—what power source should I connect this to? In most keyboard designs, I assume it would be tied to +5V, but in this case, would you recommend +5V, VSW, or perhaps +3.3V?

Also, I’m a bit confused about the +3.3V rail in the schematic. Where does it originate? Does it come from the VDD pin of the E73 MCU?

I’m still a beginner when it comes to schematic design, so I hope my questions aren’t too silly. Thanks in advance for your help!

ebastler, 2025-04-13:
Hi!

No worries about the questions. The power supply scheme on these boards is quite confusing after all :D Too many separate voltage domains and too many chips and parts involved.

The different voltage domains on this guide all have different reasons. I'll try to explain it a little. Not sure if it is clear the way I explain. Feel free to ask in more detail if you need!

+5V is the power coming from USB. It is always 5V.

+VSW is the power coming from battery management, and will be from battery (if battery powered) or from USB (if plugged in). +VSW can be about the entire battery voltage range plus a bit of tracking voltage from the charging chip - so ~ 3V to 4.5V depending on battery charge level.

VDD is only used as IO voltage for the MCU itself (and, in the example you listed, generated by the MCU itself as well). All signals cominmg from the MCU will be at VDD (3.3V with default setup, I tend to run mine a bit lower at 2.8V for slightly better battery life). The nRF52 has a built-in DC-DC converter that creates the 3.3V it needs (and also 1.8V which it also needs internally) from +VSW.

UG_LV and UG_HV is a signal level shifter. It lifts the RGB data signal from VDD up to VSW, since 3.3V signal would not be enough data voltage for the WS2812 to reliably work within specs. This chip has nothing to do with power/supplies, it only boosts the data line.

UG_PWR is the same as +VSW, but it is switched on/off by Q3. WS2812 consume quite a lot of power even when they are turned off, so they would chug the battery empty in no time. Therefore, Q3 turns the WS2812 off when not in use. You don't connect anything else to UG_PWR - it is supplied through Q3, and the LEDs use the power.

So to sum it up, the WS2812 run at the same voltage as +VSW (but with Q3 as a power switch in line with the supply), and the data signal (UG_HV) is at the same voltage as +VSW as well.

Gasiro, 2025-05-07:
Thank you so much — your explanation was super clear, and I now understand everything much better!

Turns out the issue that had me stuck for several days was indeed (as always!) a voltage problem 😅 I was using the Adafruit firmware for flashing, but it didn’t set UICR_REGOUT0 to VOUT_3V3, so the VDD was stuck at 1.8V. The keyboard was technically working, but of course, none of the LEDs lit up. 😆

Now that I’ve fixed that, everything is running smoothly. Really appreciate your designguide! 🙏

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

ebastler, 2025-05-08:
Glad to hear it is working now! I see, this can be tricky to debug...

With 1.8V signal the 2N7002 for the highside switch will most likely not work yet, so the power never gets turned on for the LEDs.

Enjoy your board!

Closed 2025-05-08.

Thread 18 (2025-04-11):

Question about ebyte IC

vinniefranco, 2025-04-11:
Hello!

Am I correct in the assertion that there is no LDO to get 3V3 and it comes from C19 out from the IC?

ebastler, 2025-04-13:
Hi! Yup. The nRF52840 chip has a built-in DC-DC voltage regulator to create the 3.3V VDD supply it needs. L3 and C12 are essential for this DC-DC converter as well, and need to be placed (very) close to pins 25 and 19 as well.

vinniefranco, 2025-04-13:
Thank you! and sorry, for not using the same references as the project! In my schematic the references are L5 and C19

When you say very close, is this sufficient?

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

Thank you!

ebastler, 2025-04-13:
This is plenty close! Looks great.

vinniefranco, 2025-04-13:
Thank you!

Closed 2025-04-13.

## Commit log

2022-03-04 prepare to move to kicad 6
2022-03-04 slight schematic changes, move to marbastlib
    [zmk-schem.kicad_sch]
2022-03-05 deleted kicad 5 only files
    [zmk-schem.sch]
2022-08-31 switched to marbastlib
    [designguide-schematic.kicad_pcb, designguide-schematic.kicad_sch]
2022-08-31 began writing and drawing rev3, reached battery management part
    [designguide-schematic.kicad_sch, zmk-schem.sch]
2022-10-10 readied battery management, usb, mcu parts
    [designguide-schematic.kicad_sch]
2022-10-10 added schematic screenshot for moko
2022-10-10 re-made images, finished schematic
    [designguide-schematic.kicad_sch]
2022-10-10 included all pictures in the doc, changed underglow led model
    [designguide-schematic.kicad_sch]
2022-10-12 fixed ToC, added back to top buttons
2022-10-12 fixed missing connection in batt protections, add disclaimer to readme
    [designguide-schematic.kicad_sch]
2022-12-29 fixed wrong rotation of p-ch FET in underglow supply
    [designguide-schematic.kicad_sch]
2023-04-04 fixes #9, moves the project over to KiCad 7.0 and marbastlib PCM version instead of submodule
    [designguide-schematic.kicad_sch]
2024-06-23 Address issue #10, add ebyte e73 module, add thermistor for bq24075, rework USB filtering to follow USB specs
    [designguide-schematic.kicad_sch]
